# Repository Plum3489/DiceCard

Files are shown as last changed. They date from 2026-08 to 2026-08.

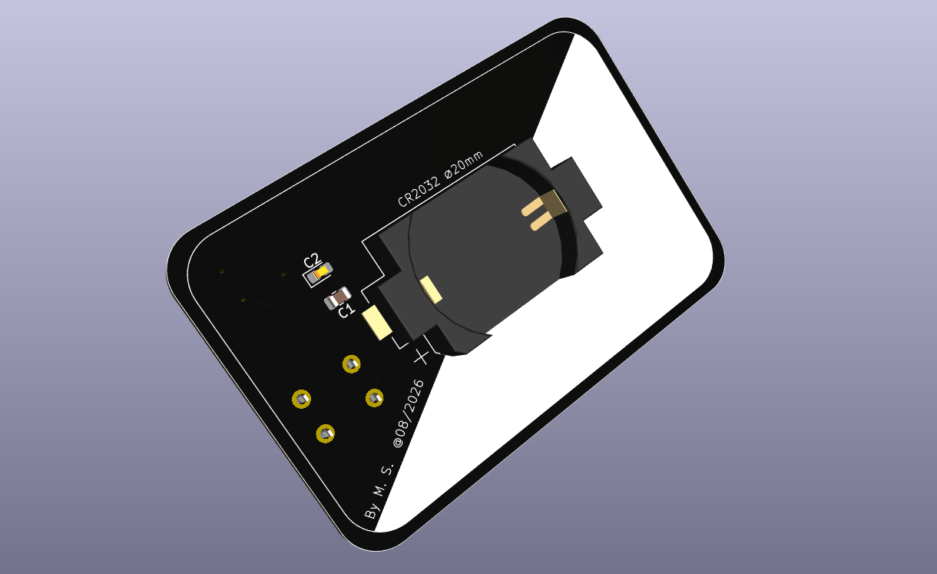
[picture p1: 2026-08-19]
hardware/images/boardback.png

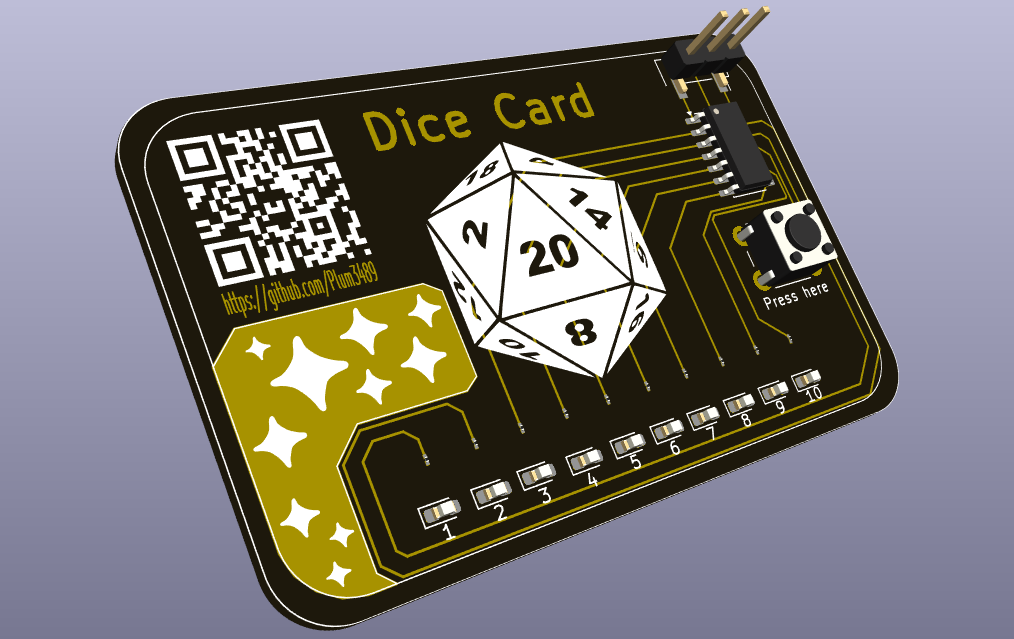
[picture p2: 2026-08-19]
hardware/images/boardfront.png

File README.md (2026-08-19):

# DiceCard

A buisiness-card-sized, battery-powered electronic dice roller :D 
Its build around the **ATtiny1614-SSN**, 10 LEDs, and a single button. 

## Instructions
1. Press to wake
2. short-press to pick a die
3. hold to roll
It goes back to sleep when it's done.

boardfront

boardback

## Features

- 7 selectable dice  **d2, d4, d6, d8, d10**, plus two special modes:
  - **"1" -> d20**: two chained d10 rolls, LED-animated, you sum the results
  - **"9" -> d100**: tens-digit roll + units-digit roll (flat 1-100)
  - Deep sleep (power-down) between uses -> wakes only on button press
  - Only a single button

## Bill of materials (BOM)
| Amount | Part | Notes | Price | Links | | | | | |
|---|---|---|---|---|---|---|---|---|---|
| 1x | ATtiny1614 | | 1,05€ | https://www.reichelt.de/de/de/shop/produkt/8-bit-attiny_avr-risc_mikrocontroller_16_kb_20_mhz_soic-14-335590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 | | | | | |
| 1x | Cap 0805, 1 µF | | 0,08€ | https://www.reichelt.de/de/de/shop/produkt/mlcc_0805_1_f_16_v_x7r_-10_h1_25_mm-429214 | | | | | |
| 10x | LED, SMD 0603 Red | | 0,07€ | https://www.reichelt.de/de/de/shop/produkt/led_smd_0603_rot_56_mcd_100_-231657 | | | | | |
| 10x | Resistor, SMD 0402 2,2 kOhm | | 0,02€ | https://www.reichelt.de/de/de/shop/produkt/smd-widerstand_0402_2_2_kohm_63_mw_1_-182934 | | | | | |
| 1x | Cap 1206 100nF | | 0,04€ | https://www.reichelt.de/de/de/shop/produkt/mlcc_1206_100_nf_100_v_-10_x7r-409241 | | | | | |
| 1x | Battery Holder Ø 20 mm | | 0,67€ | https://www.reichelt.de/de/de/shop/produkt/knopfzellenclip_fuer_20_mm_smd-74686 | | | | | |
| 1x | UDPI-Programming Board | IF NEEDED. ONLY ONE. YOU DONT NEED THEM PER BOARD | 7,50€ | https://www.berrybase.de/adafruit-updi-friend-3v-5v-stromversorgung-ch340e-chip-usb-c-3v-5v-1k-rueckkopplungswiderstand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 | | | | | |
| 1x | PCB | | ~4€ | | | | | | |
| Total  | ---------- | ---------- | 6,74€ (+7,50€) | | | | | | |

## Pin Map
| Silkscreen label | ATtiny1614 pin | Function |
|---|---|---|
| D1 | PA2 | LED |
| D2 | PA3 | LED |
| D3 | PA4 | LED |
| D4 | PA5 | LED |
| D5 | PA6 | LED |
| D6 | PA7 | LED |
| D7 | PB3 | LED |
| D8 | PB2 | LED |
| D9 | PB1 | LED |
| D10 | PB0 | LED |
| — | PA1 | Button (to GND, internal pull-up) |
| — | PA0 | UPDI (programming only) |
| — | VCC | CR2032 + |
| — | GND | CR2032 − |

Schematic

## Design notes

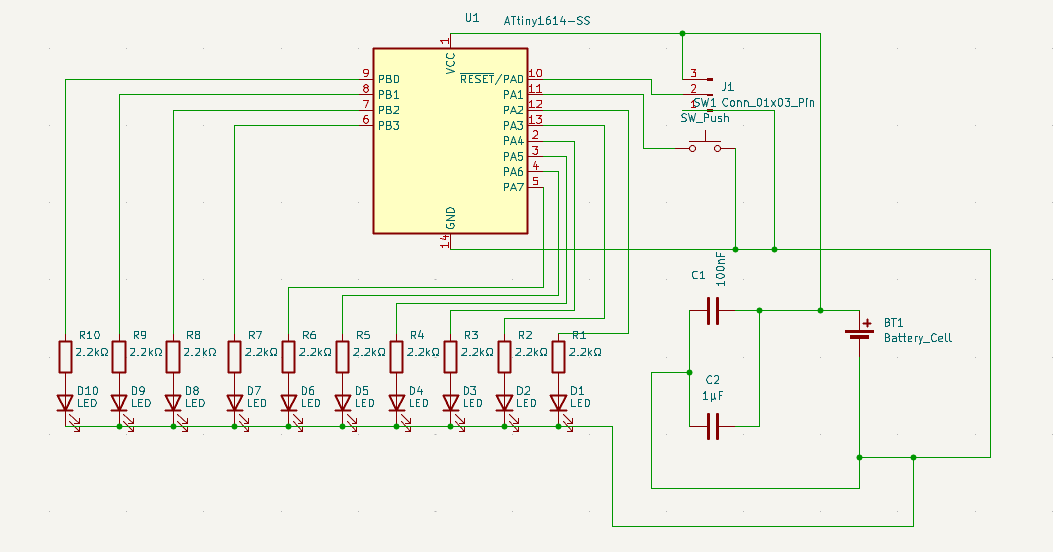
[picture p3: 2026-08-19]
hardware/images/Schematic.png

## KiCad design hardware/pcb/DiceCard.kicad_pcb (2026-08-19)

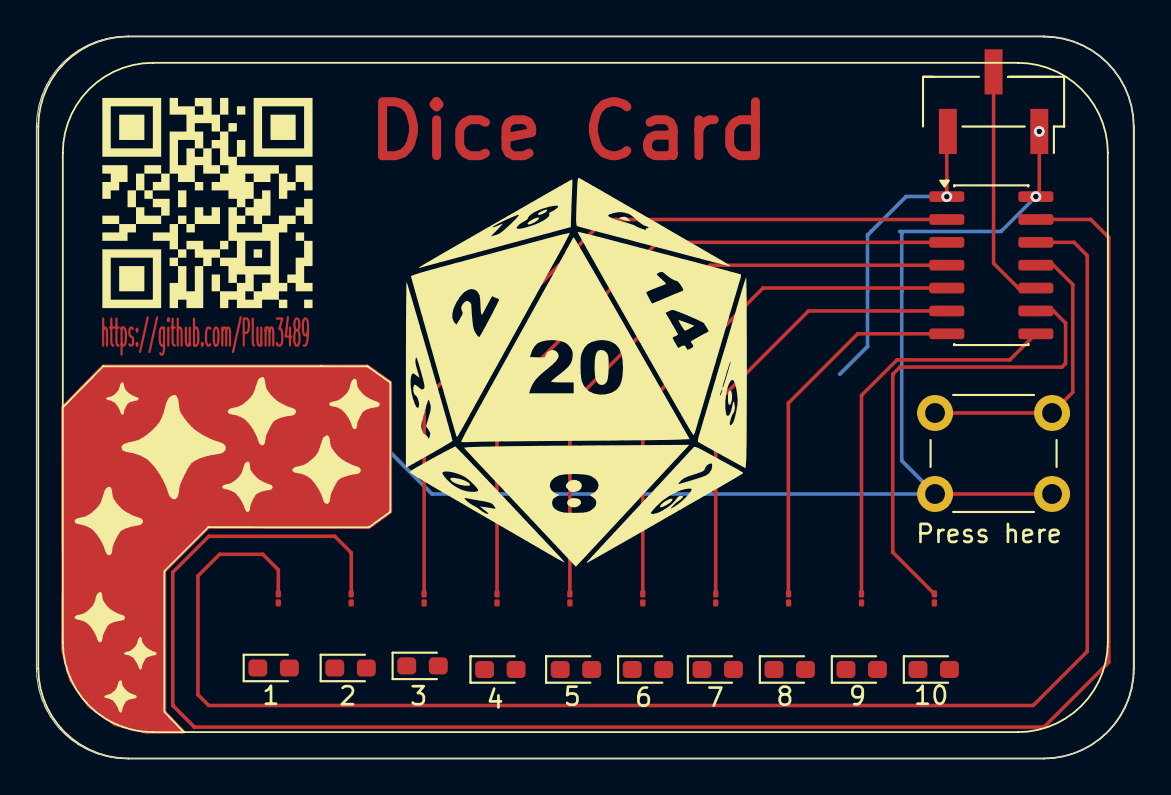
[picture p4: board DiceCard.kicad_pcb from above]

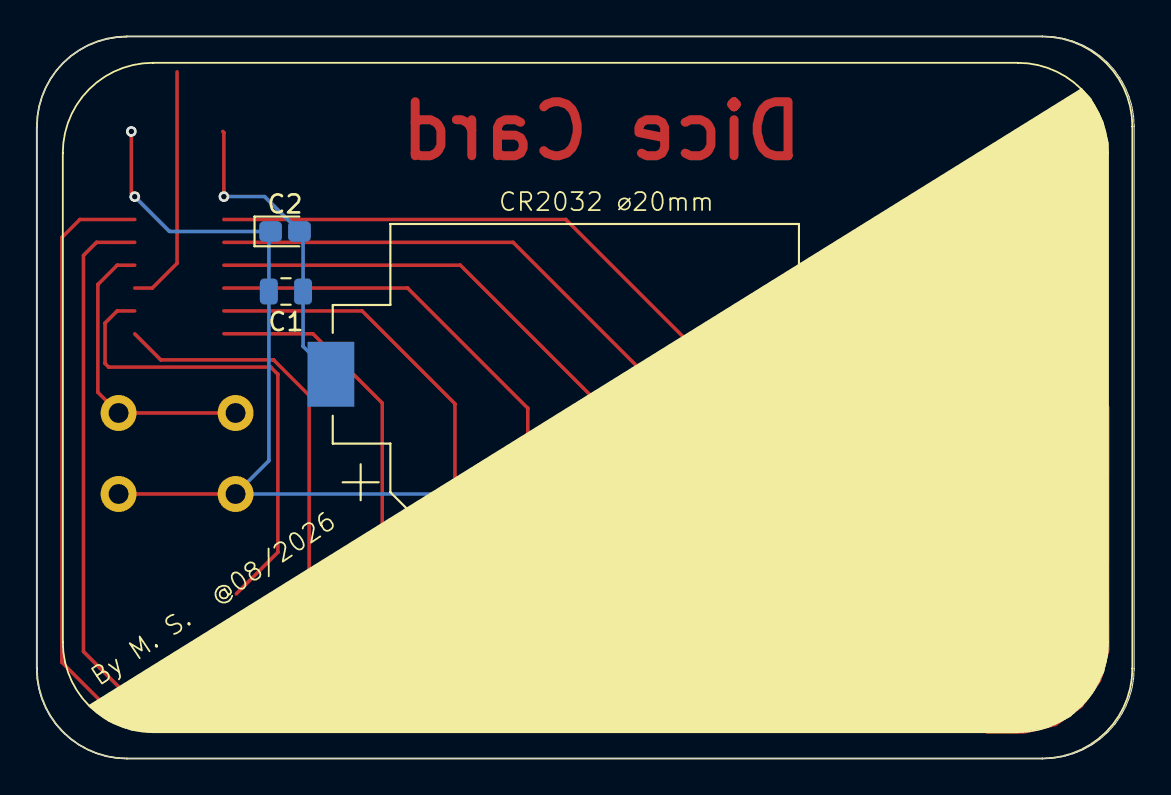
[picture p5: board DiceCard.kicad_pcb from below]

Board: 2 copper layers, 61.0 x 40.1 mm, 26 parts (3 on the bottom side), 24 nets.

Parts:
1, 2, 3, 4, 5, 6, 7, 8, 9, 10: LED; LED_0603_1608Metric_Pad1.05x0.95mm_HandSolder
BT1: Battery_Cell; BatteryHolder_Keystone_1060_1x2032
C1: 100nF; C_0805_2012Metric
C2: 1µF; CP_EIA-1608-08_AVX-J_HandSolder
J1: Conn_01x03_Pin; PinHeader_1x03_P2.54mm_Vertical_SMD_Pin1Right
Press here: SW_Push; SW_PUSH_6mm
R1, R2, R3, R4, R5, R6, R7, R8, R9, R10: 2.2kΩ; R_01005_0402Metric
U1: ATtiny1614-SS; SOIC-14_3.9x8.7mm_P1.27mm

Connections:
unnamed: BT1.1 (+), C1.1, C2.2, J1.3, U1.1 (VCC)
unnamed: 1.1 (K), 2.1 (K), 3.1 (K), 4.1 (K), 5.1 (K), 6.1 (K), 7.1 (K), 8.1 (K), 9.1 (K), 10.1 (K), BT1.2 (-), C1.2, C2.1, J1.1, Press here.2, U1.14 (GND)
unnamed: 1.2 (A), R1.2
unnamed: 2.2 (A), R2.2
unnamed: 3.2 (A), R3.2
unnamed: 4.2 (A), R4.2
unnamed: 5.2 (A), R5.2
unnamed: 6.2 (A), R6.2
unnamed: 7.2 (A), R7.2
unnamed: 8.2 (A), R8.2
unnamed: 9.2 (A), R9.2
unnamed: 10.2 (A), R10.2
unnamed: J1.2, U1.10 (~RESET/PA0)
unnamed: Press here.1, U1.11 (PA1)
unnamed: R1.1, U1.12 (PA2)
unnamed: R2.1, U1.13 (PA3)
unnamed: R3.1, U1.2 (PA4)
unnamed: R4.1, U1.3 (PA5)
unnamed: R5.1, U1.4 (PA6)
unnamed: R6.1, U1.5 (PA7)
unnamed: R10.1, U1.9 (PB0)
unnamed: R9.1, U1.8 (PB1)
unnamed: R8.1, U1.7 (PB2)
unnamed: R7.1, U1.6 (PB3)

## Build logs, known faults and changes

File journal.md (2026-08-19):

---
title: "DiceCard"
github: "https://github.com/Plum3489/DiceCard"
description: "A business-card-sized, battery-powered electronic dice roller :D"
created_at: "2026-08-18"
---

# First hour: Trying to figure things out
Before starting the project I wrote done the rough idea I head about what I was gonna make.
Then I started searching for parts...
It was quite the hustle, also because I couldn't decinde if I should use KiCad or EasyEDA, as I was more familiar with KiCad but in the guide-files they have used EasyEDA.
I decided on using KiCad.
ALSO as Aliexpress and other shipping companies from china now have a 3€ tarif per Item, it was more cost effective to search for parts in local online shops, therefore I needed to find out if I could even get the parts, which I needed for the project.
At this stage I've used AI to find out how I could make this project quite cheap. 

SO THATS WHY I DECIDED TO DITCH MICROCONTROLLER BOARDS and thus started using the UDPI manually programmed ATtiny-1614.
My first time using it and therefore designing a board for it.

kicad
First Schematic, testing around

# Hours 2-3: Big switcharounds
At this point I started switching around and figuring out different parts. And thats where I decided to also switch from the through-hole parts, which I (and a lot of other ppl) usually use, to SMDs.
I don't know if I'll regret this when I start soldering everything together when the time comes, but it is what it is.

kicad2
Later design

# Hours 3-6: DESIGN HELL
From then on I got tired. And everything begun to feel really tedious. I wanted to make my board look really cool. But again, again and again some things went wrong...
It was also my first time trying to make my PCB look like something special.
I learned how to use images and text etc.
BUT SOME THINGS I JUST COULD NOT FIGURE OUT. 
And I think, that I would've needed more pcb layers by now.
Things like, making a copper area and adding the f-mask back on again, to make black stars with a white soldermask outline on them.
Buuuuttt it is what it is, and I am actually quite happy on how my first hackcard turned out :>

kicad3
First Board! :D

otherdesign
Another design I had!

Also I originally wanted to add a moon, but I needed to remove it because of my solder and f-mask problem :/
mond

# Rest of the time: Coding
Some time has sadly been logged wrong by Wakatime as my coding project wasnt the same name as my project on hackatime.
So around 3 hours were lost :/
But I still have my code done, and I wont write it again.
Sadly, I will only now if it works as soon as I can test it on the hardware.
BUT I AM SO HAPPY TO BE DONE WITH THIS PROJECT!
I've learned so much and it gave me a lot more motivation to continue to working on my other projects. It was a nice switcharound and made me quite happy <3

Small code Snippet:
code

Final Design!
boardfront
boardback
Schematic

Total time spent: ~10 Hours (rounded down)

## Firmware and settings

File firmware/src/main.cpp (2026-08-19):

/*
      DiceCard - ATtiny1614-SSN
-------------------------------------

Code for my Dice Card, first time using the chip itself instead of a microcontroller board :P

PIN MAP:
    D1  = PA2      D6  = PA7
    D2  = PA3      D7  = PB3
    D3  = PA4      D8  = PB2
    D4  = PA5      D9  = PB1
    D5  = PA6      D10 = PB0
    Button = PA1 (button to GND, internal pull-up, active LOW)
    PA0 = UPDI (not used as GPIO)
*/




#include <Arduino.h>
#include <avr/sleep.h>
#include <avr/interrupt.h>

#define D100_TENS_UNITS METHOD true

const uint16_t LONG_PRESS_MS = 550;
const uint16_t DEBOUNCE_MS = 25;

// Pins
const uint8_t ledPins[10] = {
  PIN_PA2, // D1
  PIN_PA3, // D2
  PIN_PA4, // D3
  PIN_PA5, // D4
  PIN_PA6, // D5
  PIN_PA7, // D6
  PIN_PB3, // D7
  PIN_PB2, // D8
  PIN_PB1, // D9
  PIN_PB0  // D10
};
const uint8_t BTN = PIN_PA1;

// Selectable Die
const uint8_t dieOptions[7] = {1, 2, 4, 6, 8, 9, 10};
const uint8_t NUM_OPTIONS = 7;

// Methods

void allOff(){
  for(uint16_t i = 0; i<10; i++) digitalWrite(ledPins[i], LOW);
}

void allOn(){
  for(uint16_t i = 0; i<10; i++) digitalWrite(ledPins[i], HIGH);
}

void lightOnly(uint8_t idx){
  for (uint8_t i = 0; i < 10; i++) digitalWrite(ledPins[i], i == idx ? HIGH : LOW);
}

bool buttonPressed(){
  return digitalRead(BTN) == LOW;
}

void waitForPressStart(){ while (!buttonPressed()) { /* spin */ }
  delay(DEBOUNCE_MS);
  while (!buttonPressed()) { /* debounce glitch, keep waiting */ }
}

// Blocks until either the button is released before LONG_PRESS MS -> returns false
// or the hold time reaches LONG_PRESS_MS -> returns true immediately
bool waitForPressOutcome() {
  waitForPressStart();
  uint32_t start = millis();
  while (buttonPressed()) {
    if (millis() - start >= LONG_PRESS_MS) {
      return true; // long press threshold reached -> go roll now
    }
  }
  delay(DEBOUNCE_MS);
  return false; // released early -> short press
}

// sleepy eepy
volatile bool wokeUp = false;

void wakeISR(){
  wokeUp = true;
}

void goToSleep() {
  allOff();
  wokeUp = false;

  attachInterrupt(digitalPinToInterrupt(BTN), wakeISR, FALLING);

  set_sleep_mode(SLEEP_MODE_PWR_DOWN);
  cli();
  sleep_enable();
  sei();
  sleep_cpu();      // <-- CPU halts here until button press wakes it, because energy saving :>
  sleep_disable();

  detachInterrupt(digitalPinToInterrupt(BTN));

  // debounce the waking press, then wait for it to be released
  // before we start listening for menu presses.
  delay(DEBOUNCE_MS);
  while (buttonPressed()) { /* wait out the wake press */ }
  delay(DEBOUNCE_MS);
}

// Animations
// Rolls a "faces"-sided die, declaring the chase.
// goes to the result and holds 2 secs. Then it turns off.
uint8_t rollAndShow(uint8_t faces) {
  uint8_t resultIdx = random(0, faces); // 0..faces-1

  const uint8_t loops = 3; // full spins before landing
  uint16_t totalSteps = (uint16_t)loops * faces + resultIdx + 1;

  for (uint16_t i = 0; i < totalSteps; i++) {
    uint8_t idx = i % faces;
    lightOnly(idx);

    uint16_t remaining = totalSteps - i;
    uint16_t d = map(remaining, 1, totalSteps, 220, 35); // decelerate
    delay(d);
  }

  lightOnly(resultIdx);
  delay(2000);
  allOff();

  return resultIdx + 1;
}

void performRoll(uint8_t dieCode){
  if(dieCode == 1){
    // Special case d20 -> two d10s, youre gonna read the sum
    rollAndShow(10);
    delay(150);
    rollAndShow(10);
  }else if (dieCode == 9) {
    #if D100_TENS_UNITS_METHOD
        // SPECIAL: d100 => tens-digit roll (0-9, shown as faces 1-10 wher
        rollAndShow(10);
        delay(150);
        rollAndShow(10);
    #else
        // literal spec: two d10 rolls, reader adds them together
        rollAndShow(10);
        delay(150);
        rollAndShow(10);
    #endif
      } else {
        // normal die: dieCode itself is the number of faces
        rollAndShow(dieCode);
      }
}

// Setup and loop
void setup(){
  for(uint8_t i = 0; i < 10 ; i++) pinMode(ledPins[i], OUTPUT);
  allOff();
  pinMode(BTN, INPUT_PULLUP);
}

void loop(){
  goToSleep();
  randomSeed(micros());

  allOn();
  delay(600);
  allOff();
  delay(150);

  // Selection "menu"-thing
  uint8_t selection = 0;
  while(true){
      lightOnly(selection); // show current with corresponding LED
    bool longPress = waitForPressOutcome();

    if (longPress) {
      break; // hold -> roll this die now
    } else {
      selection = (selection + 1) % NUM_OPTIONS; // short press -> next option
    }
  }

  allOff();
  delay(150);

  // roll this thing :D
  performRoll(dieOptions[selection]);

  // loops back to Sleep
}
